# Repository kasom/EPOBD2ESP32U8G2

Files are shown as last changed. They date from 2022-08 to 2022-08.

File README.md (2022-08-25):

# EPOBD2ESP32U8G2
A standalone tool to automatically turn the DRLs off when parked. Can retrieves some interesting information such as battery SoC/SoH    and display it on an optional LCD or on a web browser via WiFi. (Both   station mode and softAP mode are supported.)

Refer to EPOBD2ESP32U8G2.ino for required hardware/software/libraries.

How-to build and flash the firmware (in Thai): https://docs.google.com/document/d/1qaYg5mrZ_Z40dH1lxLXlk56CZIjCwT55KqKhTERk0e0/edit?usp=sharing

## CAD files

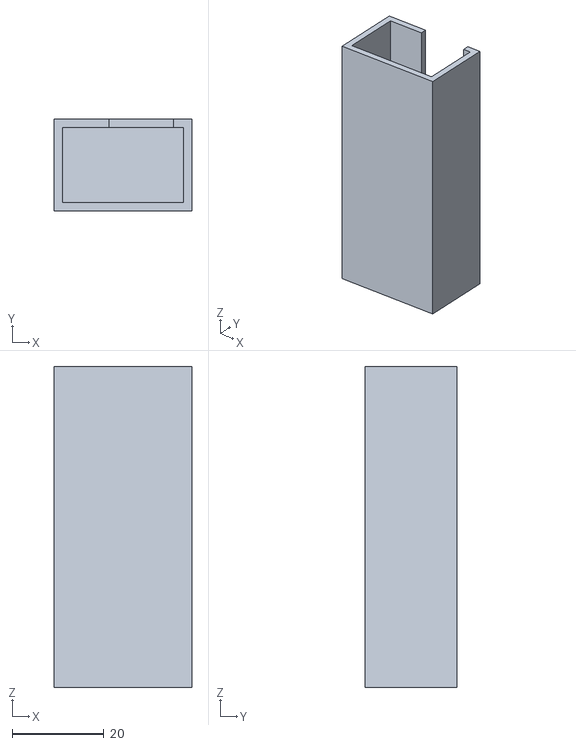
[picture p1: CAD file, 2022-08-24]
box/box-esp32-lite.stl
30.0 x 20.0 x 70.0

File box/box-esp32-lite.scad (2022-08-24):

socket_height=14;
socket_width=33.7;
box_width=30;
box_height=70;
box_depth=20;
wall_thickness=1.8;

difference() {
    cube([box_width,box_depth,box_height],center=true);
    
    translate([0,0,wall_thickness]) {
        cube([box_width-wall_thickness*2,box_depth-wall_thickness*2,box_height],center=true);
    }
    translate([4,box_depth/2,box_height/2-socket_width/2]) {
        cube([socket_height,10,socket_width+0.2],center=true);
    }    
}

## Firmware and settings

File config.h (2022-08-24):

#define USE_LCD
#define USE_WEB_INTERFACE
#ifdef USE_WEB_INTERFACE
# define USE_OTA_WEB_UPDATER
#endif


#define ESP32_LITE
//#define ESP32_DEV_KIT_V1


#ifdef ESP32_LITE
# define LED_PIN GPIO_NUM_22
# define LED_INVERT 1
#elif defined ESP32_DEV_KIT_V1
# define LED_PIN GPIO_NUM_2
# define LED_INVERT 0
#else
# error Choose ESP32_LITE or ESP32_DEV_KIT_V1
#endif

#define PUSH_BUTTON_PIN GPIO_NUM_0

#define CAN_TX GPIO_NUM_17
#define CAN_RX GPIO_NUM_16
//#define CAN_TX GPIO_NUM_23
//#define CAN_RX GPIO_NUM_18

#define LOCAL_UDP_PORT 2345
#define WEB_SERVER_PORT 80

#define OUR_NAME "EP-OBD2"

#define DEFAULT_STA_MODE_EN false
#define DEFAULT_AP_MODE_EN true

#define DEFAULT_SOFT_AP_SSID OUR_NAME
#define DEFAULT_SOFT_AP_PASS "EV for Everyone"

#define DEFAULT_STA_AP_SSID "HOME-SSID-HERE"
#define DEFAULT_STA_AP_PASS "HOME-PASSWORD-HERE"

#define BUTTON_SHORT_PRESS_MILLI  50
#define BUTTON_LONG_PRESS_MILLI   500
#define BUTTON_RESET_WARNING 3000
#define BUTTON_RESET_CONFIRM 6000

#define WIFI_AUTO_RECONNECT_INTERVAL_MS 30000

#define OBD2_POLLING_DELAY_MS 300
#define GWM_AUTH_TIMEOUT 3000
#define TESTERPRESENT_DELAY_MS 1000

#define BMS_ID 0x7e5
#define VCU_ID 0x7e3
#define BCM_ID 0x740
#define GWM_ID 0x710

#define CAN_SEND_BUFFER_SIZE 10

#ifdef USE_LCD
#   define DEFAULT_LCD_CONTRAST 65
#   define DEFAULT_LCD_BRIGHTNESS 64

#   define LCD_BL_FREQUENCY 5000
#   define LCD_BL_CHANNEL 0
#   define LCD_BL_RESOLUTION 8
#   define LCD_BL_PIN 4

// ESP32 VSPI
#   define LCD_CLK GPIO_NUM_18
// Actually, the LCD doesn't have MISO
#   define LCD_MISO GPIO_NUM_19
#   define LCD_MOSI GPIO_NUM_23
#   define LCD_CS GPIO_NUM_5

#   ifdef ESP32_LITE
#     define LCD_DC GPIO_NUM_2
#   elif defined ESP32_DEV_KIT_V1
#     define LCD_DC GPIO_NUM_22
#   endif

#   define LCD_RESET GPIO_NUM_15
#endif

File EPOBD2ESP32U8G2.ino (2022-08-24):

const char info_text[] PROGMEM = R"rawliteral(
/*
  EP-OBD2-ESP32-U8G2

  Version 1
  
  A standalone tool to automatically turn the DRLs off when parked.
  Can retrieves some interesting information such as battery SoC/SoH 
  and display it on an optional LCD or on a web browser via WiFi. (Both
  station mode and softAP mode are supported.)

  https://github.com/kasom/EPOBD2ESP32U8G2

  Copyright 2022, Kasom
  
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

  Hardware:
  
     1. ESP32 dev board
     2. CAN bus transceiver module (3.3v) (Tested: SN65HVD230DR)
           ***Take the 120 Ohm resister (if available) out from the board.*** 
           Our tool is a stub, not the end of the CAN bus.
           The terminating resistors are already in the car.
     3. OBD2 male connector + cable
     4. 128x64 COG 3.3v SPI LCD module (ST7565R/12864) (optional, for the LCD)
     5. USB cables, soldering iron, solder wire, box, etc.
     6. PC or Mac to build/flash the code
     

  ***LCD_K*** to GND via 180 Ohm resistor
     
  | ESP32 Dev K. | ESP32 Lite | CAN Tran. | LCD Module        |Blt-in  LED|  SW  |
  |--------------|------------|-----------|-------------------|-----------|------|
  |     3V3      |      3V    |  3V3/VCC  |  LCD_VDD          |           |      |
  |     GND      |      G     |   G/GND   |LCD_VSS,***LCD_K***|           |   X  |
  |  *GPIO_2*    |  *GPIO_22* |           |                   |     X     |      |
  |   GPIO_16    |   GPIO_16  |  CAN_RX   |                   |           |      |
  |   GPIO_17    |   GPIO_17  |  CAN_TX   |                   |           |      |
  |   GPIO_5     |   GPIO_5   |           | LCD_CS            |           |      |
  |   GPIO_15    |   GPIO_15  |           | LCD_RSE           |           |      |
  |  *GPIO_22*   |  *GPIO_2*  |           | LCD_RS (DC)       |           |      |
  |   GPIO_18    |   GPIO_18  |           | LCD_SCL           |           |      |
  |   GPIO_23    |   GPIO_23  |           | LCD_(MO)SI        |           |      |
  |   GPIO_4     |   GPIO_4   |           | LCD_A             |           |      |

  Softwares and libraries:
     
     https://www.arduino.cc/
       Arduino IDE 1.8.19
       
     https://github.com/espressif/arduino-esp32
       Arduino core for ESP32
       
     https://github.com/me-no-dev/AsyncTCP
     https://github.com/me-no-dev/ESPAsyncWebServer
        Web Server        
        
     https://github.com/me-no-dev/arduino-esp32fs-plugin
        Arduino ESP32 filesystem uploader (for the web interface)
       
     https://github.com/olikraus/u8g2 
        U8g2 graphic library (optional, for the LCD)
  
  
                                [Web browser via PC/Tablet/Mobile]
                                                |
                                                :
                                                |
                                    ---------------------
                                    | WiFi Access Point |
                                    ---------------------
                                                   |
                                                   : (WiFi station mode)
                                                   |
     ------------    -------------------     ---------------     --------
     | CAR OBD2 | -- | CAN transceiver | --- | ESP32 board | --- | GLCD |
     ------------    -------------------     ---------------     --------
                                                   |
                                                   : (WiFi softAP mode)
                                                   |
                               [Web browser via PC/Tablet/Mobile]
  
  References/tutorials:

     https://play.google.com/store/apps/details?id=com.moonoi.mgep&hl=en_US&gl=US
     https://www.youtube.com/watch?v=busKOFT2vug 
     https://github.com/openvehicles/Open-Vehicle-Monitoring-System-3/tree/master/vehicle/OVMS.V3/components/vehicle_mgev/src
     https://docs.espressif.com/projects/esp-idf/en/release-v4.1/api-reference/peripherals/can.html
     https://docs.espressif.com/projects/arduino-esp32/en/latest/installing.html
     https://randomnerdtutorials.com/getting-started-with-esp32/
     https://summivox.wordpress.com/2019/05/31/obd-2-in-bullet-points-and-examples/
     https://en.wikipedia.org/wiki/ISO_15765-2
     https://www.mgevs.com/threads/where-is-the-obd2-port-on-an-mg5.1386/ (mg5_data_extended.txt)
     https://github.com/peternixon/MG-EV-OBD-PID/find/main
     
 */
)rawliteral";

#include "config.h"

/*****************************************************************************/

#if !defined( ESP32 )
  #error This code is intended to run on the ESP32 platform! Please check your Tools->Board setting.
#endif

String version_string=String("Firmware compiled : ") + String(__DATE__ " " __TIME__ "\n") + "Built for " 
#ifdef ESP32_LITE
                + "ESP32 Lite"
#elif defined ESP32_DEV_KIT_V1
                + "ESP32 Dev Kit v1"
#else
                + "unknown configuration"
#endif
                + "\n";


#include <WiFi.h>
#include <AsyncTCP.h>
#include <ESPAsyncWebServer.h>
#include <WiFiClient.h>
#include <WiFiUdp.h>
#include <driver/gpio.h>
#include <driver/can.h>
#include <Preferences.h>
#include <nvs_flash.h>
#include <SPIFFS.h>
#include <ESPmDNS.h>
#include <ArduinoJson.h>
#ifdef USE_OTA_WEB_UPDATER
# include <Update.h>
#endif
#include <Preferences.h>
#include "LCD.h"
#include "AutoPollingMessages.h"

WiFiUDP wifiUDP;
AsyncWebServer server(WEB_SERVER_PORT);
AsyncWebSocket ws("/ws");

const char *our_name=OUR_NAME;

const char *preference_name=our_name;

const char *default_soft_ap_ssid = DEFAULT_SOFT_AP_SSID;
const char *default_soft_ap_pass = DEFAULT_SOFT_AP_PASS;

const char *default_sta_ap_ssid = DEFAULT_STA_AP_SSID;
const char *default_sta_ap_pass = DEFAULT_STA_AP_PASS;

String local_ip="";

bool wifi_ap_on=false;
bool wifi_sta_on=false;

bool wifi_was_disconnected=false;

enum DRL_STATES { DRL_AUTO, DRL_OFF, DRL_ON };
enum DRL_CONTROLS { DRL_TURN_ON, DRL_TURN_OFF, DRL_DO_NOTHING };
enum LED_STATES { LED_STATE_DRL_AUTO, LED_STATE_DRL_OFF, LED_STATE_DRL_ON, LED_STATE_RESET_WARNING, LED_STATE_RESETTING };
uint32_t led_patterns[]={ 0x00000001, 0x00000011, 0x00000111, 0x55555555, 0xf5f5f5f5 };

DRL_STATES target_drl_state=DRL_AUTO;
DRL_CONTROLS drl_control=DRL_DO_NOTHING;

DRL_STATES previous_target_drl_state=DRL_AUTO;
DRL_CONTROLS previous_drl_control=DRL_DO_NOTHING;
char previous_gear_pos=' ';


unsigned long previousMillisWifiRetry = 0;
unsigned long previousMillisOBD2Polling = 0;

int pollingHead = 0;
volatile bool autoPolling = true;
volatile bool gwmAuthRequest = false;
unsigned long lastReceived = 0;
unsigned long lastPollStart=0;
unsigned long lastStartAuth=0;

SemaphoreHandle_t canBusSendSemaphore;
can_message_t canMessages[CAN_SEND_BUFFER_SIZE];
unsigned char canMessageHead=0;
unsigned char canMessageTail=0;

float hvb_SoH=0.0;
float hvb_SoC=0.0;
float hvb_coolant_temp=0.0;
float hvb_v=0.0;
float hvb_a=0.0;
char gear_pos=' ';
float dc_dc_temp=0.0;
float dc_dc_v=0.0;
float dc_dc_a=0.0;
float dc_dc_w=0.0;
float motor_coolant_temp=0.0;
float motor_temp=0.0;
int charging_status=0;
char charging_status_text[20]="";
unsigned long odometer=0;

char can2udp_ip[128]="";
uint16_t can2udp_port=0;
bool can2udp_enable=false;

void wiFiEvent(WiFiEvent_t event) {
  switch (event) {
    case ARDUINO_EVENT_WIFI_STA_START:
        Serial.println("WiFi client started");
#ifdef USE_LCD
        lcd_wifi_status=LCD_WIFI_DISCONNECTED;
        break;
#endif
    case ARDUINO_EVENT_WIFI_STA_CONNECTED:
        Serial.println("Connected to access point");
        wifi_was_disconnected=false;
#ifdef USE_LCD
        lcd_wifi_status=LCD_WIFI_CONNECTED_HIGH;
#endif
        break;
    case ARDUINO_EVENT_WIFI_STA_DISCONNECTED:
        if (wifi_sta_on) {
          if (!wifi_was_disconnected) {
            Serial.println("Disconnected from WiFi access point");
            wifi_was_disconnected=true;
#ifdef USE_LCD
            lcd_wifi_status=LCD_WIFI_DISCONNECTED;
#endif
            WiFi.disconnect();
          }
        }
        break;
    case ARDUINO_EVENT_WIFI_STA_GOT_IP:
        Serial.print("Obtained IP address: ");
        Serial.println(WiFi.localIP());
        local_ip=WiFi.localIP().toString();
#ifdef USE_LCD
        strcpy(lcd_text,local_ip.c_str());
#endif
        break;
    case ARDUINO_EVENT_WIFI_AP_START:
        Serial.println("WiFi access point started");
#ifdef USE_LCD
        lcd_ap_status=LCD_AP_ON;
#endif
        break;
    default: break;
  }
}

void reset_all_data() {
  nvs_flash_erase();
  nvs_flash_init();
  //SPIFFS.format();
  ESP.restart();
}

void webMain(AsyncWebServerRequest *request) {
  bool has_web=SPIFFS.exists("/web/index.htm");
  request->redirect(has_web?"/web/index.htm":"/web-update");
}

void getInfo(AsyncWebServerRequest *request) {
  char buffer[2048];

  sprintf(buffer,"{ "
            "\"hvb_SoH\": %f, "
            "\"hvb_SoC\": %f, "
            "\"coolant_temp\": %f, "
            "\"hvb_v\": %f, "
            "\"hvb_a\": %f, "
            "\"gear_pos\": \"%c\", "
            "\"dc_dc_temp\": %f, "
            "\"dc_dc_v\": %f, "
            "\"dc_dc_a\": %f, "
            "\"dc_dc_w\": %f, "
            "\"motor_coolant_temp\": %f, "
            "\"motor_temp\": %f, "
            "\"charging_status\": %d, "
            "\"charging_status_text\": \"%s\" "
            " }",
            hvb_SoH,
            hvb_SoC,
            hvb_coolant_temp,
            hvb_v,
            hvb_a,
            gear_pos,
            dc_dc_temp,
            dc_dc_v,
            dc_dc_a,
            dc_dc_w,
            motor_coolant_temp,
            motor_temp,
            charging_status,
            charging_status_text
            );

  request->send(200, "application/json", buffer);
}

#ifdef USE_OTA_WEB_UPDATER
void firmwareUploadForm(AsyncWebServerRequest *request) {
  
  const char firmware_upload_form[] PROGMEM = R"rawliteral(

<script src='https://ajax.googleapis.com/ajax/libs/jquery/3.2.1/jquery.min.js'></script>

<p>Firmware Update (EPOBD2ESP32U8G2.<b>ino.esp32</b>.bin)</p>

<form method='POST' action='#' enctype='multipart/form-data' id='upload_form'>
  <input type='file' name='update'>
  <input type='submit' value='Update'>
</form>

<div id='prg'>progress: 0%</div>

<script>
  $('form').submit(function(e) {
    e.preventDefault();
    
    var form = $('#upload_form')[0];
    var data = new FormData(form);
    
    $.ajax({
      url: '/firmware-update',
      type: 'POST',
      data: data,
      contentType: false,
      processData: false,
      xhr: function() {
        var xhr = new window.XMLHttpRequest();
        xhr.upload.addEventListener('progress', function(evt) {
          if (evt.lengthComputable) {
            var per = evt.loaded / evt.total;
            $('#prg').html('progress: ' + Math.round(per*100) + '%');
          }
        }, false);
        
        return xhr;
        },
        success:function(d, s) {
          console.log('success!')
        },
        error: function (a, b, c) {
       }
    });
  });
</script>

)rawliteral";

  request->send(200, "text/html", firmware_upload_form);
}

void firmwareUpdateHandler(AsyncWebServerRequest *request) {
  request->send(200, "text/plain", (Update.hasError()) ? "FAIL" : "OK");
  ESP.restart();
}

void firmwareUploadingFileHandler(AsyncWebServerRequest *request, String filename, size_t index, uint8_t *data, size_t len, bool final)  {
  if (index==0) {
    // start
#ifdef USE_LCD
    strcpy(lcd_text,"UPDATING...");
    updateLCDScreen();
#endif
    Serial.printf("Update firmware: %s\r\n", filename.c_str());
    if (!Update.begin(UPDATE_SIZE_UNKNOWN)) { //start with max available size
      Update.printError(Serial);
    }
  }
  
  if (len) {
    /* flashing firmware to ESP*/
    if (Update.write(data, len) != len) {
      Update.printError(Serial);
    }
  }
  if (final) {
    if (Update.end(true)) { //true to set the size to the current progress
      Serial.println("Update Success.");
      Serial.println("Rebooting...");
    } else {
      Update.printError(Serial);
    }
  }
}

bool webUpdateHasError=false;

void webUploadForm(AsyncWebServerRequest *request) {
  const char web_upload_form[] PROGMEM = R"rawliteral(

<script src='https://ajax.googleapis.com/ajax/libs/jquery/3.2.1/jquery.min.js'></script>

<p>Web Update (EPOBD2ESP32U8G2.<b>spiffs</b>.bin)</p>

<form method='POST' action='#' enctype='multipart/form-data' id='upload_form'>
  <input type='file' name='update'>
  <input type='submit' value='Update'>
</form>

<div id='prg'>progress: 0%</div>

<script>
  $('form').submit(function(e) {
    e.preventDefault();
    
    var form = $('#upload_form')[0];
    var data = new FormData(form);
    
    $.ajax({
      url: '/web-update',
      type: 'POST',
      data: data,
      contentType: false,
      processData: false,
      xhr: function() {
        var xhr = new window.XMLHttpRequest();
        xhr.upload.addEventListener('progress', function(evt) {
          if (evt.lengthComputable) {
            var per = evt.loaded / evt.total;
            $('#prg').html('progress: ' + Math.round(per*100) + '%');
          }
        }, false);
        
        return xhr;
        },
        success:function(d, s) {
          console.log('success!')
        },
        error: function (a, b, c) {
       }
    });
  });
</script>

)rawliteral";

  request->send(200, "text/html", web_upload_form);
}

void webUpdateHandler(AsyncWebServerRequest *request) {
  request->send(200, "text/plain", (webUpdateHasError) ? "FAIL" : "OK");
  ESP.restart();
}

void webUploadingFileHandler(AsyncWebServerRequest *request, String filename, size_t index, uint8_t *data, size_t len, bool final)  {
  if (index == 0) {
    // start
#ifdef USE_LCD
    strcpy(lcd_text,"WEB UPDATE...");
    updateLCDScreen();
#endif
    Serial.printf("Update web: %s\r\n", filename.c_str());
    if (!Update.begin(UPDATE_SIZE_UNKNOWN,U_SPIFFS)) { //start with max available size
      Update.printError(Serial);
    }
  }
  if (len) {
    /* flashing  SPIFFS */
    if (Update.write(data, len) != len) {
      Update.printError(Serial);
    }
  }
  if (final) {
    if (Update.end(true)) { //true to set the size to the current progress
      Serial.println("Update Success.");
      Serial.println("Rebooting...");
    } else {
      Update.printError(Serial);
    }
  }
}

#endif

void listAllFiles(){
 
  File root = SPIFFS.open("/");
 
  File file = root.openNextFile();
 
  while(file){
 
      Serial.print("FILE: ");
      Serial.println(file.name());
 
      file = root.openNextFile();
  }
 
}

void getInfoText(AsyncWebServerRequest *request) {
  request->send(200, "text/plain", version_string+"Local ip: "+(local_ip==""?"not connected":local_ip)+"\n"+info_text);
}

void getWiFiConfig(AsyncWebServerRequest *request) {
  AsyncResponseStream *response = request->beginResponseStream("application/json");
  DynamicJsonDocument json(1024);

  Preferences preferences;
  preferences.begin(preference_name, true); // open in read-only mode

  json["ap_mode_en"] = preferences.getBool("ap_mode_en",DEFAULT_AP_MODE_EN);
  json["soft_ap_ssid"] = preferences.getString("soft_ap_ssid",default_soft_ap_ssid);
  json["soft_ap_pass"] = preferences.getString("soft_ap_pass",default_soft_ap_pass);
  
  json["sta_mode_en"] = preferences.getBool("sta_mode_en",DEFAULT_STA_MODE_EN);  
  json["sta_ap_ssid"] = preferences.getString("sta_ap_ssid",default_sta_ap_ssid);
  json["sta_ap_pass"] = preferences.getString("sta_ap_pass",default_sta_ap_pass);

  preferences.end();

  serializeJson(json, *response);
  request->send(response);
}

void getCAN2UDPConfig(AsyncWebServerRequest *request) {
  AsyncResponseStream *response = request->beginResponseStream("application/json");
  DynamicJsonDocument json(1024);

  Preferences preferences;
  preferences.begin(preference_name, true); // open in read-only mode

  json["can2udp_ip"] = preferences.getString("can2udp_ip",can2udp_ip);
  json["can2udp_port"] = preferences.getUShort("can2udp_port",can2udp_port);
  json["can2udp_enable"] = preferences.getBool("can2udp_enable",can2udp_enable);
  
  preferences.end();

  serializeJson(json, *response);
  request->send(response);
}


#ifdef USE_LCD
void lcdAdjust(AsyncWebServerRequest *request) {
  char buffer[100];

  Preferences preferences;

  preferences.begin(preference_name, false); // open in read-write mode

  int brightness=preferences.getInt("lcd_brightness",DEFAULT_LCD_BRIGHTNESS);
  int contrast=preferences.getInt("lcd_contrast",DEFAULT_LCD_CONTRAST);

  if (request->hasParam("contrast")) {
    contrast = request->getParam("contrast")->value().toInt();
    setLCDContrast(contrast);
    preferences.putInt("lcd_brightness",contrast);
    Serial.println("New contrast: " + contrast);
  }
  if (request->hasParam("brightness")) {
    brightness = request->getParam("brightness")->value().toInt();
    setLCDBrightness(brightness);
    preferences.putInt("lcd_brightness",brightness);
    Serial.println("New brightness: " + brightness);
  }

  preferences.end();

  sprintf(buffer,"{ \"brightness\" : %d, \"contrast\" : %d }",brightness,contrast);

  request->send(200, "application/json", buffer);
}
#endif
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
void loop() {
  unsigned long currentMillis = millis();

  if (processButton()) return; // do nothing else if the user want to reset

  ws.cleanupClients();
  
  char message_buffer[256];

  gwmAuth(NULL,currentMillis);
  bcm(NULL,currentMillis,DRL_DO_NOTHING);
  
  can_message_t message;
  
  if (can_receive(&message, pdMS_TO_TICKS(50)) == ESP_OK) {
    can2str(&message,message_buffer);
    decodeCAN(&message,currentMillis);

    if (can2udp_enable && can2udp_ip[0]!=0 && can2udp_port!=0 && WiFi.status()==WL_CONNECTED) {
      wifiUDP.beginPacket(can2udp_ip,can2udp_port);
      wifiUDP.write((const uint8_t *)message_buffer,strlen(message_buffer));
      wifiUDP.endPacket();
    }

    Serial.printf("send %s\r\n",message_buffer);
    ws.textAll(message_buffer);
  }

  resolveDRLState(currentMillis);

  if (xSemaphoreTake(canBusSendSemaphore,(TickType_t)10)) {
    while (canMessageHead!=canMessageTail) {
        if (can_transmit(&canMessages[canMessageHead], pdMS_TO_TICKS(50)) == ESP_OK) {
          // Good
          can2str(&canMessages[canMessageHead],message_buffer);
          strcpy(message_buffer+strlen(message_buffer)," (S)");
          ws.textAll(message_buffer);
        } else {
          ws.textAll("DBG: Failed to queue message for transmission");
        }

        canMessageHead++;
        
        if (canMessageHead==CAN_SEND_BUFFER_SIZE) {
          canMessageHead=0;
        }
    }

    xSemaphoreGive(canBusSendSemaphore);
  }
      
#ifdef USE_LCD
  if (wifi_sta_on) {
    if (WiFi.status()==WL_CONNECTED) {
      if (WiFi.RSSI()>-60) {
        lcd_wifi_status=LCD_WIFI_CONNECTED_HIGH;
      } else {
        lcd_wifi_status=LCD_WIFI_CONNECTED_LOW;
      }
    } else {
      lcd_wifi_status=LCD_WIFI_DISCONNECTED;
    }
  }

  updateLCDScreen();
#endif

  // if WiFi is down, try reconnecting
  if (wifi_sta_on && (WiFi.status() != WL_CONNECTED) && (currentMillis - previousMillisWifiRetry >=WIFI_AUTO_RECONNECT_INTERVAL_MS)) {
    Serial.println("Try reconecting WiFi.");
    wifi_was_disconnected=false;
    WiFi.reconnect();
    previousMillisWifiRetry = currentMillis;
  }

  if (autoPolling && (currentMillis - previousMillisOBD2Polling >= OBD2_POLLING_DELAY_MS)) {
    enqueueCANMessage(&auto_polling_messages[pollingHead]);
    if (pollingHead==0) {
      lastPollStart=currentMillis;
    }
    pollingHead++;

    if (pollingHead==NUM_AUTO_POLLING_CAN_MESSAGES) {
      pollingHead=0;
    }

    previousMillisOBD2Polling = currentMillis;
  }
  
  yield();
}
